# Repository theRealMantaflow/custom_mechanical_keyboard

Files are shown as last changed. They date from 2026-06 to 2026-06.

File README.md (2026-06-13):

# Custom STM32 Mechanical Keyboard

This repository contains the hardware design files (PCB schematics and mechanical enclosures) for a custom mechanical keyboard. The PCB is designed in **KiCad**, and the case/mechanical components are modeled in **FreeCAD**.

## Features

* **Microcontroller:** STM32F405RGT
* **Connectivity:** USB-C 2.0 with dedicated ESD protection (USBLC6-2SC6)
* **Switch Matrix:** 6x16 layout supporting up to 96 keys
* **Switches:** Cherry MX compatible, utilizing Khail hot-swap sockets
* **Anti-Ghosting:** Per-key diodes for full N-Key Rollover (NKRO)
* **Extras:** Support for a rotary encoder and broken-out SWD/I2C pins for easy debugging and expansion

## Repository Structure

* `/` - Contains the KiCad project, schematics, and PCB layout files.
* `/case/` - Contains the FreeCAD design files for the keyboard case and plate.
* `/pcbway_production/` - Contains the gerber files.

## Prerequisites & Environment Setup

Before opening the KiCad project files, you need to configure your KiCad environment with the appropriate custom libraries and plugins used in this design. 

### KiCad Package Installation

Follow these steps exactly to ensure all footprints and symbols load correctly:

1. **Add the ebastler repository:**
   * Open KiCad and go to the **Plugin and Content Manager**.
   * Click on **Manage Repositories** (usually at the bottom left).
   * Add a new repository with the following URL:
     [https://raw.githubusercontent.com/ebastler/KiCad-repository/main/repository.json](https://raw.githubusercontent.com/ebastler/KiCad-repository/main/repository.json)
2. **Install custom libraries:**
   * Switch the repository dropdown at the top of the Plugin Manager to the newly added `ebastler` repo.
   * Find and install the **`marbastlib`** package.
3. **Switch back to the official repository:**
   * Change the repository dropdown back to the official **KiCad** repository.
4. **Install required keyboard packages:**
   * Search for and install the **`Keyswitch KiCad Library`**.
   * *(Optional)* If you plan on modifying the PCB layout, install the **`Keyboard footprints placer`** plugin to make routing and placing switches easier.

Once these packages are installed, you can safely open the `.kicad_pro` file.

## Contributions

Feel free to fork this repository and submit pull requests if you have improvements for the PCB routing or case design. 

My Ko-fi link if you wanna support my efforts: Ko-fi [Kofi](https://ko-fi.com/mantaflow)

## Thanks

Inspired from: [Modern Hobbyist](https://www.youtube.com/watch?v=u13yRbBiRYM)

## License
This project is licensed under the **GNU General Public License v3.0 (GPL-3.0)**. See the [LICENSE](LICENSE.txt) file for more details.

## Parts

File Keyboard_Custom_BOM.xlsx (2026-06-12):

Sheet: Build Summary
Component Category | Total Parts Needed | Unique Components
Keyboard Items | 31 | 6
PCB Items | 211 | 18
Total (Active) | 242 | 24

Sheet: Full Parts List
Item Description | Quantity | Unit Price | Total | Category | Status | Purchase Link
Stabs | 12 | 32 | 384 | Keyboard Items | Active | https://neomacro.in/products/cherry-pcb-mount-stabilizers-clip-in
Stabs wire set | 1 | 400 | 400 | Keyboard Items | Active | https://neomacro.in/products/equalz-c3-stabilizer-wire-set
Stabs (optional) | 1 | 999 | 999 | Keyboard Items | Discarded | https://meckeys.com/shop/accessories/keyboard-accessories/more/glorious-goat-stabilizers/
sockets | 9 | 80 | 720 | Keyboard Items | Active | https://meckeys.com/shop/accessories/keyboard-accessories/key-switches/kailh-hot-swap-socket/
switches (HMx Hyacinth v2) | 9 | 360 | 3240 | Keyboard Items | Active | https://meckeys.com/shop/accessories/keyboard-accessories/key-switches/hmx-hyacinth-v2-switch/
switches (Kailh Box Cream Pro) | 9 | 380 | 3420 | Keyboard Items | Discarded | https://meckeys.com/shop/accessories/keyboard-accessories/key-switches/kailh-box-cream-pro-switch/
MCU (STM32F405RGT6) | 2 | 462 | 924 | PCB Items | Active | https://robu.in/product/stm32f405rgt6-stmicroelectronics-arm-mcu-advanced-connectivity-and-encryption-stm32-family-stm32f4-series-microcontrollers-2/
12Mhz crystals HC49/US | 5 | 27.95 | 139.75 | PCB Items | Active | https://www.mouser.in/ProductDetail/ABRACON/ABLS2-12.000MHZ-D4Y-T?qs=LoTOQoUkC8Rn80rn3Dp9%252Bw%3D%3D
1N4148 SOD-123-2 | 100 | 3.91 | 391 | PCB Items | Active | https://www.mouser.in/ProductDetail/Panjit/1N4148W_R1_00001?qs=sPbYRqrBIVnqVztCqPNVrw%3D%3D
22pF 2012 | 10 | 14.07 | 140.7 | PCB Items | Active | https://www.mouser.in/ProductDetail/KYOCERA-AVX/0805ZA220JAT2A?qs=qVfB0%2FDaMDayn2JkoZWS9w%3D%3D
0.01uF 2012 | 10 | 15.56 | 155.6 | PCB Items | Active | https://www.mouser.in/ProductDetail/KYOCERA-AVX/0805YC103JAT2A?qs=hDfa8caAWT981330vF6Hgg%3D%3D
0.1uF 2012 | 10 | 11.83 | 118.3 | PCB Items | Active | https://www.mouser.in/ProductDetail/KYOCERA-AVX/KAM21BR71H104JM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
2.2uF 2012 | 10 | 23.57 | 235.7 | PCB Items | Active | https://www.mouser.in/ProductDetail/KYOCERA-AVX/0805YC225JAT2A?qs=%252BdQmOuGyFcHAs%2FdSKfbQcg%3D%3D
10uF 2012 | 10 | 7.27 | 72.7 | PCB Items | Active | https://www.mouser.in/ProductDetail/Walsin/0805B106K6R3CT?qs=sGAEpiMZZMuMW9TJLBQkXoaTank9xe3KyjArHnZbXP4%3D
5.1kOhm 2012 | 10 | 1.86 | 18.6 | PCB Items | Active | https://www.mouser.in/ProductDetail/YAGEO/RC0805JR-105K1L?qs=sGAEpiMZZMtlubZbdhIBIEgN9MQql2m6y5lVZltd6Tw%3D
10kOhm 2012 | 10 | 6.71 | 67.1 | PCB Items | Active | https://www.mouser.in/ProductDetail/SEI-Stackpole/RMCA0805JT10K0-UP?qs=IPgv5n7u5Qax6yYsSvtfnA%3D%3D
PPTC Fuse 3216 | 5 | 39.14 | 195.7 | PCB Items | Active | https://www.mouser.in/ProductDetail/Eaton-Electronics/PTSA120613V050
rotary encoder | 2 | 231.09 | 462.18 | PCB Items | Active | https://www.mouser.in/ProductDetail/Bourns/PEC11L-4020F-S0020?qs=fgHA1UgJI8CzObWXJBveJQ%3D%3D
Push Button | 10 | 8.67 | 86.7 | PCB Items | Active | https://www.mouser.in/ProductDetail/Same-Sky/TS02-66-70-BK-260-LCR-D?qs=A6eO%252BMLsxmRxQEfk53wqSQ%3D%3D
USB-C port with through-hole pins | 3 | 123 | 369 | PCB Items | Active | https://www.mouser.in/ProductDetail/Same-Sky/UJ20-C-H-G-SMT-TR?qs=vvQtp7zwQdMB%2FjSfD6wTAw%3D%3D
Voltage Regulator SOT-25-5 | 3 | 24.23 | 72.69 | PCB Items | Active | https://www.mouser.in/ProductDetail/Diodes-Incorporated/AP2112K-3.3TRG1?qs=x6A8l6qLYDDPYHosCdzh%2FA%3D%3D
USB TVS Diode | 10 | 27.86 | 278.6 | PCB Items | Active | https://www.mouser.in/ProductDetail/STMicroelectronics/USBLC6-2SC6?qs=po45yt2pPpu%2FhNIlwQdTlg%3D%3D
1uF 2012 | 10 | 15.37 | 153.7 | PCB Items | Discarded | https://www.mouser.in/ProductDetail/KYOCERA-AVX/KGM21AR71C105JU?qs=Jm2GQyTW%2FbgRn%252Bi87%2FZsQQ%3D%3D
PCB (converted from USD, not including import duty) | 1 | 3343.68 | 3343.68 | PCB Items | Active | JLC PCB
Grand Total (Active): | 11816

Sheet: Pivot Table_Full Parts List_1
Status | Active
Item Description | Sum - Total
0.01uF 2012 | 155.6
0.1uF 2012 | 118.3
10kOhm 2012 | 67.1
10uF 2012 | 72.7
12Mhz crystals HC49/US | 139.75
1N4148 SOD-123-2 | 391
2.2uF 2012 | 235.7
22pF 2012 | 140.7
5.1kOhm 2012 | 18.6
MCU (STM32F405RGT6) | 924
PCB (not including import duty) | 3343.68
PPTC Fuse 3216 | 195.7
Push Button | 86.7
rotary encoder | 462.18
sockets | 720
Stabs | 384
Stabs wire set | 400
switches (HMx Hyacinth v2) | 3240
USB TVS Diode | 278.6
USB-C port with through-hole pins | 369
Voltage Regulator SOT-25-5 | 72.69
Total Result | 11816

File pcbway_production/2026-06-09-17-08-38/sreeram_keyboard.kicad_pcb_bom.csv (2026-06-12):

Designator | Quantity | Value | Footprint | Package | MPN | DNP | Mount_Type | KiLib_Generator
C1, C13, C15, C3, C5, C6, C7, C8 | 8 | 0.1uF | C_0805_2012Metric_Pad1.18x1.45mm_HandSolder |  |  |  | smt | SMD_2terminal_chip_molded
C10, C9 | 2 | 2.2uF | C_0805_2012Metric_Pad1.18x1.45mm_HandSolder |  |  |  | smt | SMD_2terminal_chip_molded
C11, C12 | 2 | 22pF | C_0805_2012Metric_Pad1.18x1.45mm_HandSolder |  |  |  | smt | SMD_2terminal_chip_molded
C14, C2, C4 | 3 | 10uF | C_0805_2012Metric_Pad1.18x1.45mm_HandSolder |  |  |  | smt | SMD_2terminal_chip_molded
C16, C17 | 2 | 0.01uF | C_0805_2012Metric_Pad1.18x1.45mm_HandSolder |  |  |  | smt | SMD_2terminal_chip_molded
D1, D10, D11, D12, D13, D14, D15, D16, D17, D18, D19, D2, D20, D21, D22, D23, D24, D25, D26, D27, D28, D29, D3, D30, D31, D32, D33, D34, D35, D36, D37, D38, D39, D4, D40, D41, D42, D43, D44, D45, D46, D47, D48, D49, D5, D50, D51, D52, D53, D54, D55, D56, D57, D58, D59, D6, D60, D61, D62, D63, D64, D65, D66, D67, D68, D69, D7, D70, D71, D72, D73, D74, D75, D76, D77, D78, D79, D8, D80, D81, D82, D83, D84, D85, D86, D9 | 86 | D | D_SOD-123 |  |  |  | smt
F1 | 1 | 550mA | Fuse_1206_3216Metric_Pad1.42x1.75mm_HandSolder |  |  |  | smt | SMD_2terminal_chip_molded
J1 | 1 | USB_C_Receptacle_USB2.0_14P | USB_C_Receptacle_GCT_USB4085 |  |  |  | tht
J2, J3 | 2 | Conn_01x10_Pin | PinHeader_1x10_P2.54mm_Vertical |  |  |  | tht | connector/pin_header_socket
MX1, MX10, MX11, MX12, MX13, MX14, MX15, MX16, MX17, MX18, MX19, MX2, MX20, MX21, MX22, MX23, MX24, MX25, MX26, MX27, MX28, MX29, MX3, MX30, MX31, MX32, MX33, MX34, MX35, MX36, MX37, MX38, MX39, MX4, MX40, MX41, MX42, MX43, MX44, MX45, MX46, MX47, MX48, MX49, MX5, MX50, MX51, MX52, MX53, MX54, MX55, MX56, MX57, MX58, MX59, MX6, MX60, MX61, MX62, MX63, MX64, MX65, MX66, MX67, MX68, MX69, MX7, MX70, MX71, MX72, MX73, MX74, MX75, MX76, MX77, MX78, MX79, MX8, MX80, MX81, MX82, MX83, MX84, MX85, MX86, MX9 | 86 | MX_SW_HS | SW_MX_HS_S_CPG151101S11_1u |  |  |  | smt
R1, R2 | 2 | 5.1k | R_0805_2012Metric_Pad1.20x1.40mm_HandSolder |  |  |  | smt | SMD_2terminal_chip_molded
R3, R5, R6, R7 | 4 | 10k | R_0805_2012Metric_Pad1.20x1.40mm_HandSolder |  |  |  | smt | SMD_2terminal_chip_molded
R4 | 1 | 100k | R_0805_2012Metric_Pad1.20x1.40mm_HandSolder |  |  |  | smt | SMD_2terminal_chip_molded
S6 | 1 | TS02-66-70-BK-260-LCR-D | TS0266100BK100LCRD |  |  |  | tht
U1 | 1 | STM32F405RGTx | LQFP-64_10x10mm_P0.5mm |  |  |  | smt | package/gullwing
U2 | 1 | AP2112K-3.3 | SOT95P285X140-5N |  |  |  | smt
U3 | 1 | USBLC6-2SC6 | SOT-23-6 |  |  |  | smt | package/gullwing
U4 | 1 | PEC11L-4020F-S0020 | PEC11L4120FS0020 |  |  |  | tht
Y1 | 1 | 12Mhz | ABLS |  |  |  | smt

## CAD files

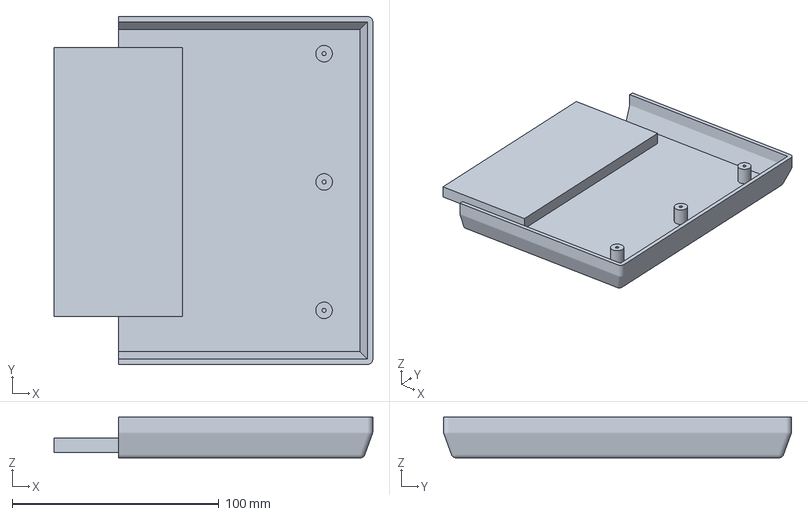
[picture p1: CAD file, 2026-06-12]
case/exports/3MF/case-RightSlice.3mf
154.0 x 168.2 x 19.8 mm

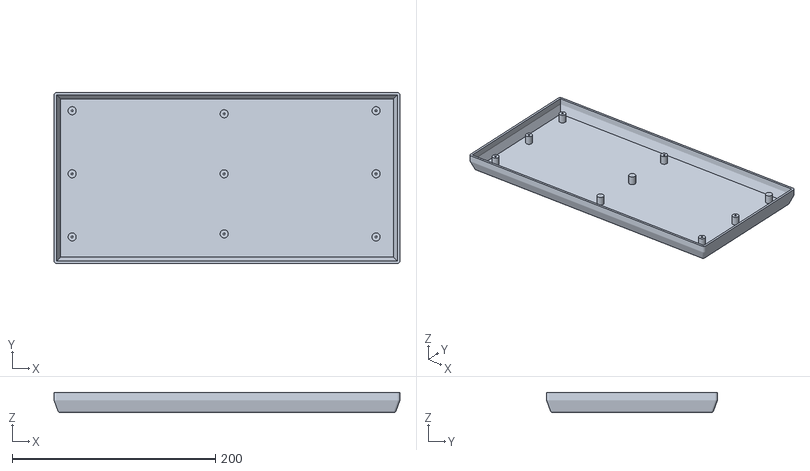
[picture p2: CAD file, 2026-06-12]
case/exports/STL/case/case-Body.stl
340.2 x 168.2 x 19.8

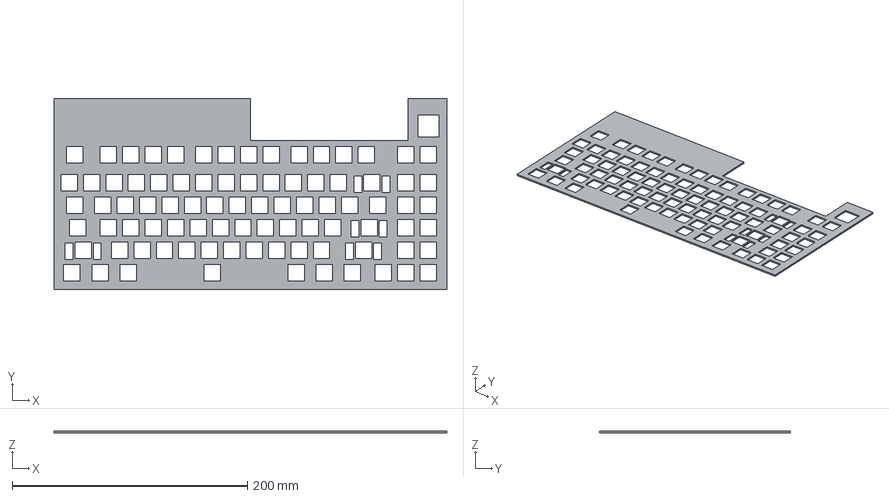
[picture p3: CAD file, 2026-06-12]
case/exports/STP/front_plate-Body.step
333.8 x 162.2 x 1.50 mm

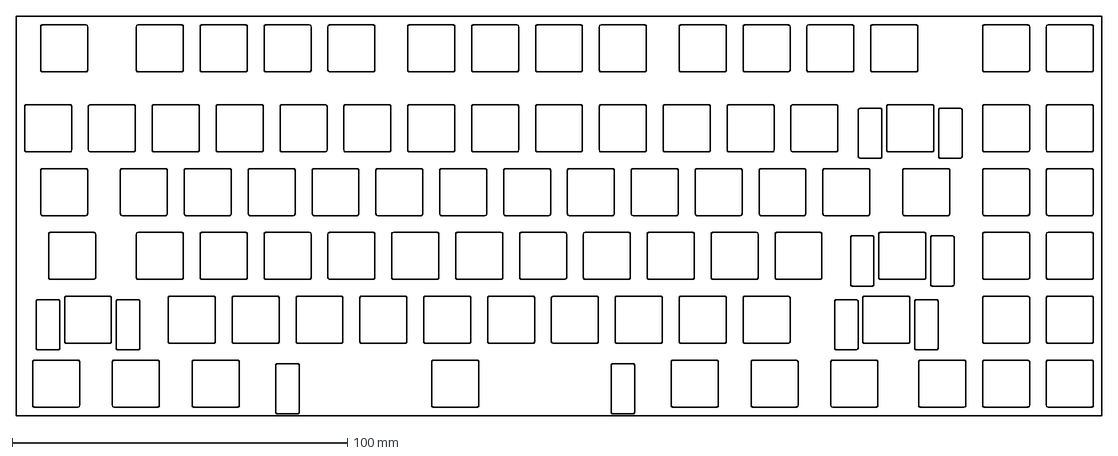
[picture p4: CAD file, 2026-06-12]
case/plate-2026-06-02T06_51_52.090Z.dxf
323.9 x 119.1 mm

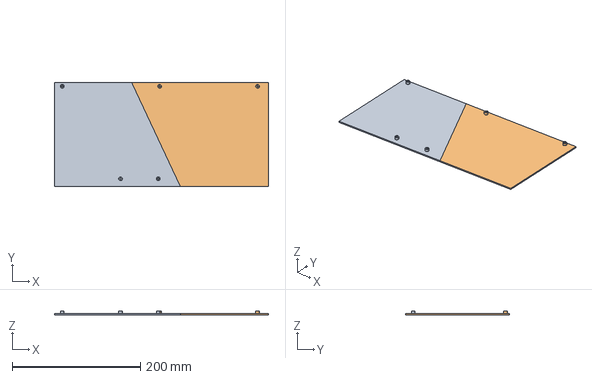
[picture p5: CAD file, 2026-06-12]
case/back_plate.FCStd
333.8 x 162.2 x 6.00 mm
LeftSlice
RightSlice

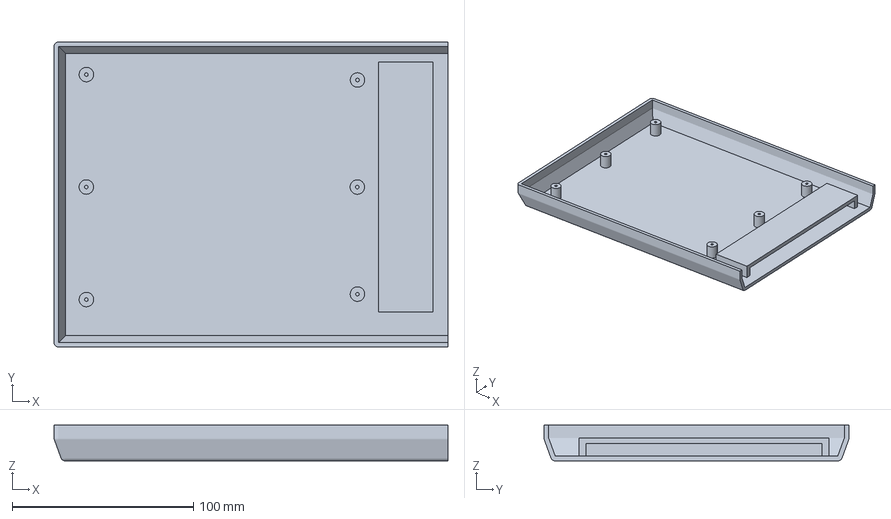
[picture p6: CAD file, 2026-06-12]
case/exports/3MF/case-LeftSlice.3mf
217.3 x 168.2 x 19.8 mm

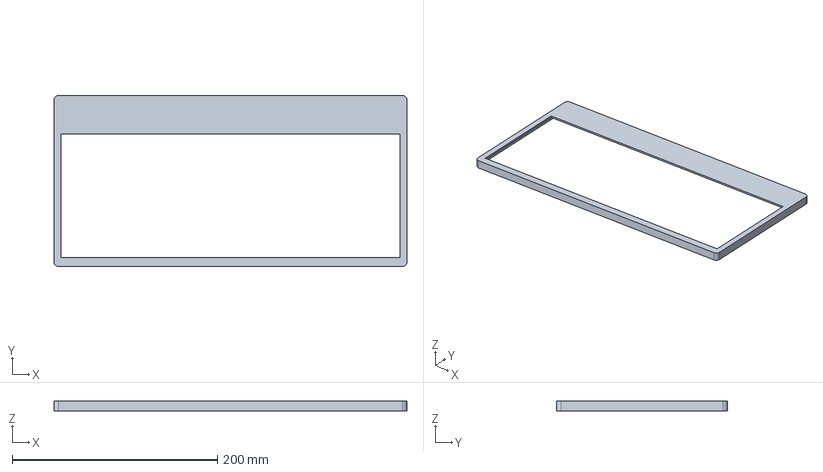
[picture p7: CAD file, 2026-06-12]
case/front_cover.FCStd
344.2 x 167.0 x 9.40 mm

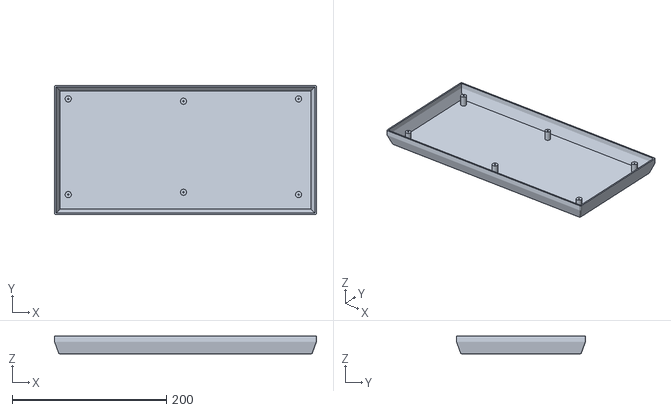
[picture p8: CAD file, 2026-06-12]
case/case-Body.stl
339.9 x 167.4 x 23.0

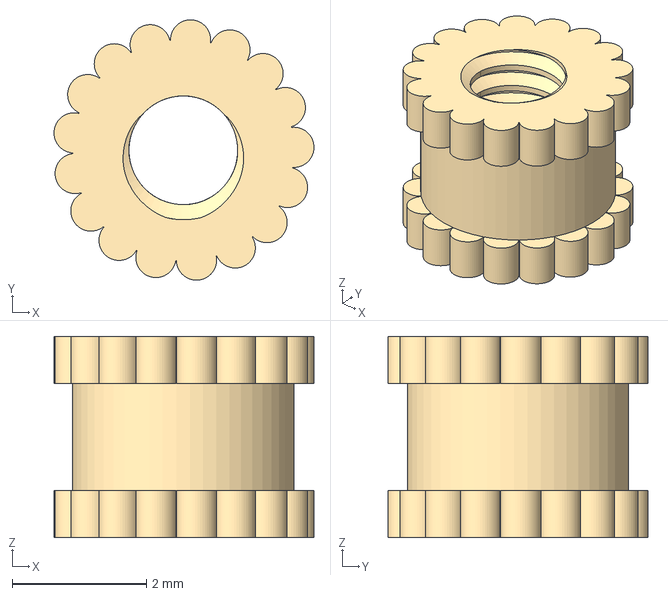
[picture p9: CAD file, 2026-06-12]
case/BI_M2x3_heat_insert.step
3.88 x 3.88 x 3.00 mm

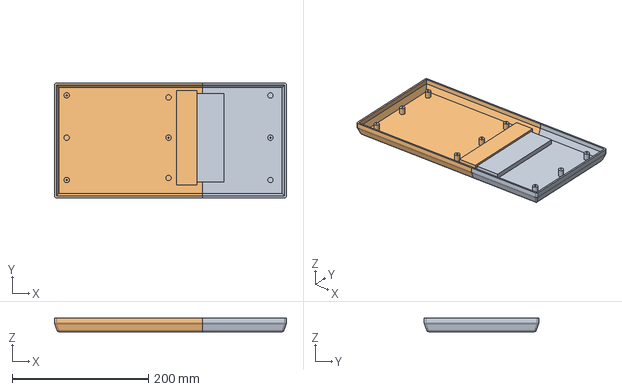
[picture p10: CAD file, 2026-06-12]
case/case.FCStd
340.2 x 168.2 x 19.8 mm
RightSlice
LeftSlice

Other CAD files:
case/front_plate.FCStd
case/exports/3MF/Old/front_plate-Body.3mf
case/exports/3MF/Old/front_cover-Body.3mf
case/exports/3MF/Old/case-Body.3mf
case/exports/3MF/Old/front_cover-BodyPocket.3mf
case/exports/3MF/Old/back_plate-Body.3mf
case/exports/STL/front_plate-Body.stl

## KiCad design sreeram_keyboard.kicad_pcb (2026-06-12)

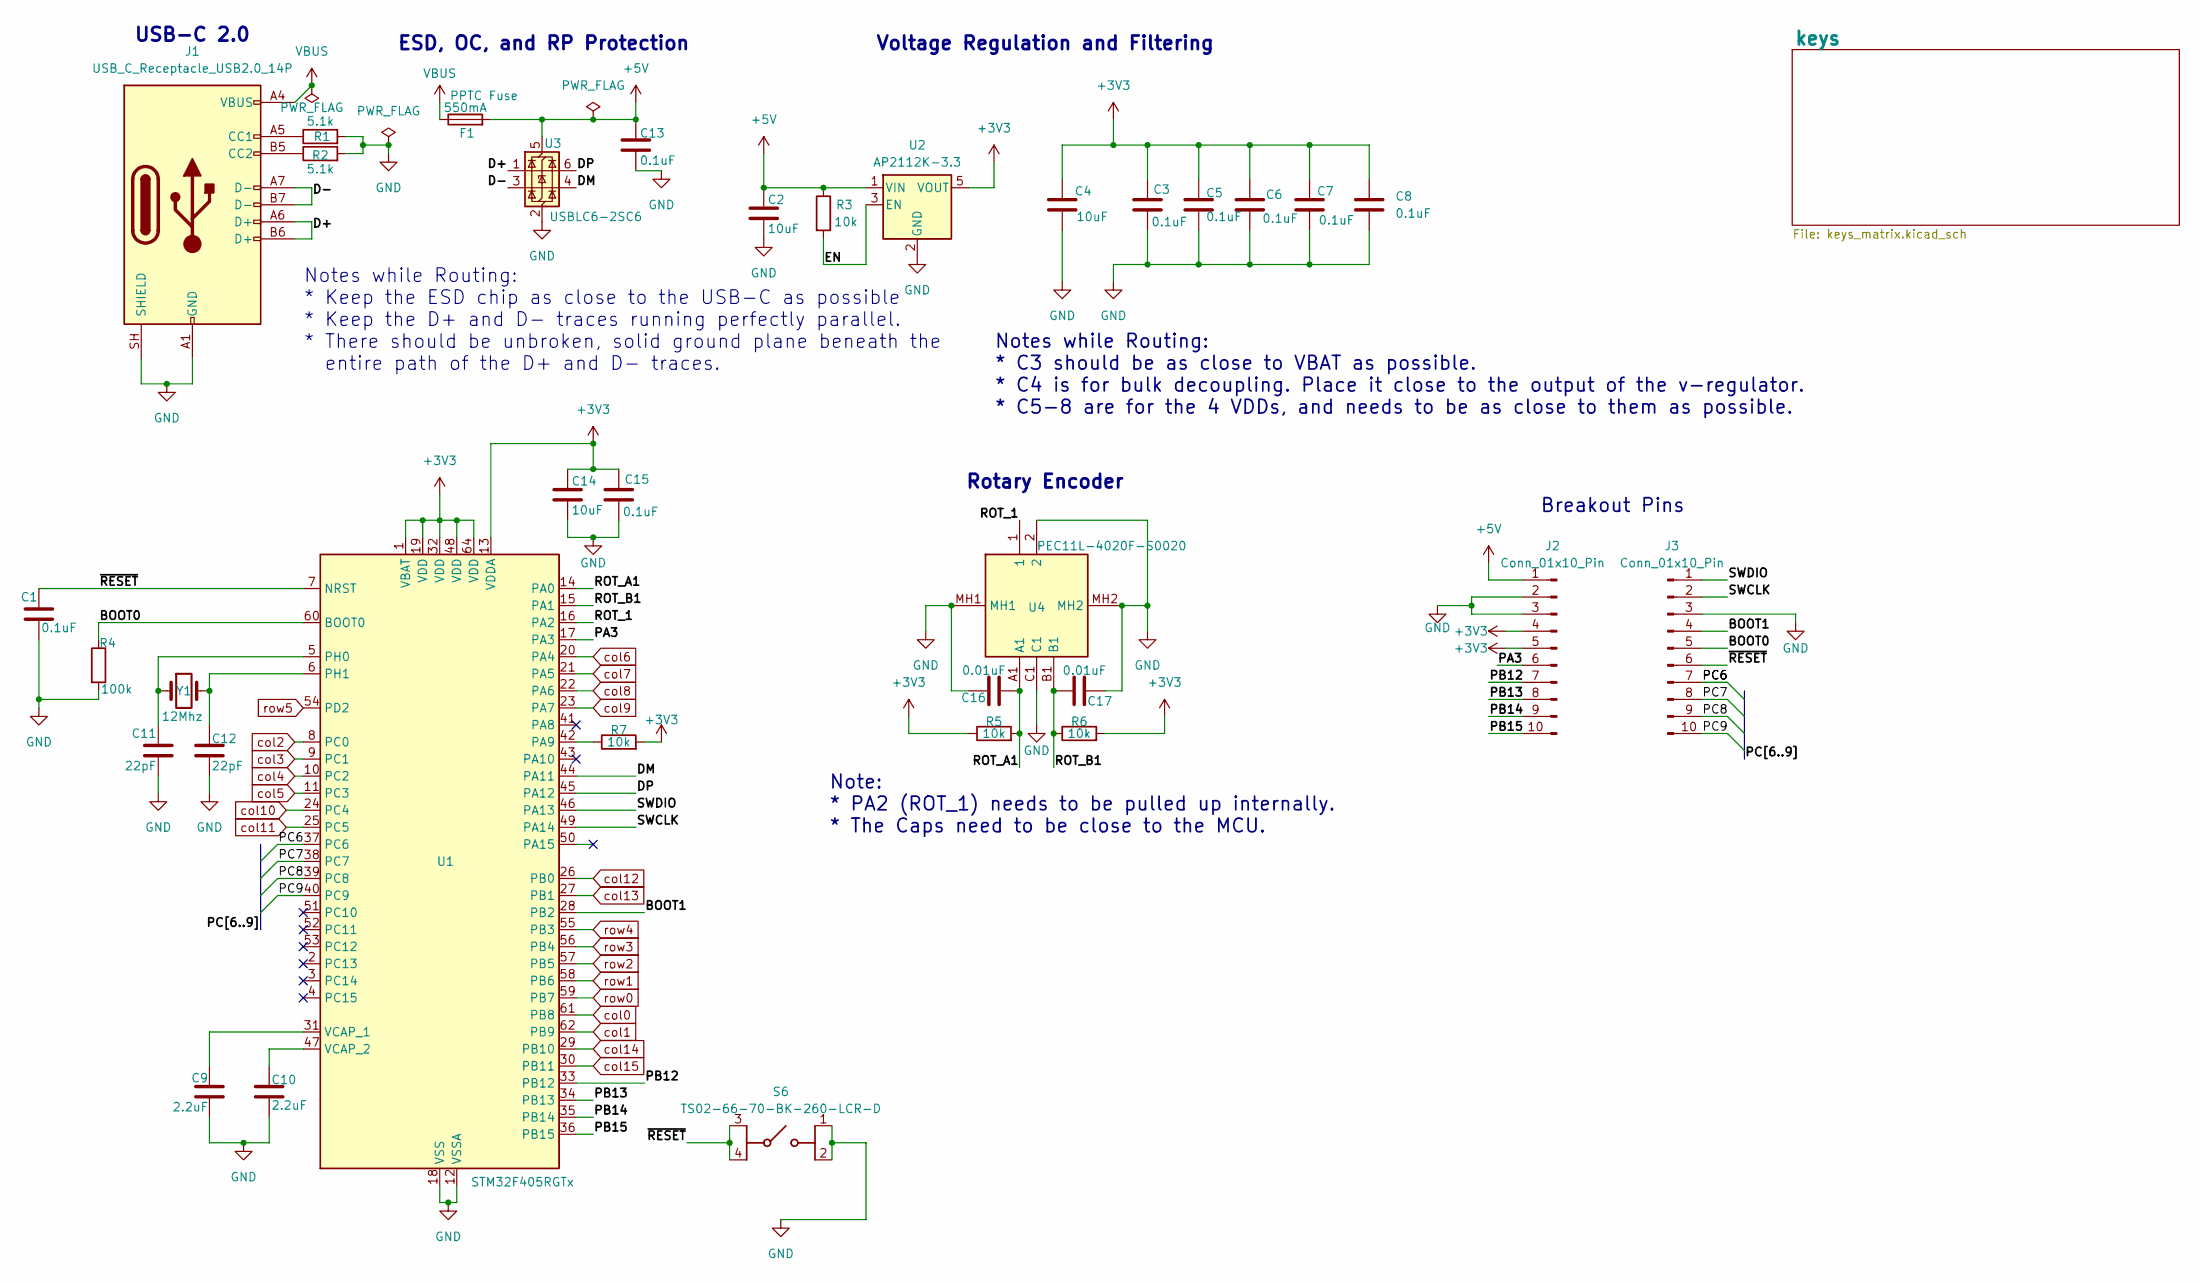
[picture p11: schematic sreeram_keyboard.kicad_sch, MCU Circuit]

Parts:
C1, C3, C5, C6, C7, C8, C13, C15: 0.1uF; C_0805_2012Metric_Pad1.18x1.45mm_HandSolder
C2, C4, C14: 10uF; C_0805_2012Metric_Pad1.18x1.45mm_HandSolder
C9, C10: 2.2uF; C_0805_2012Metric_Pad1.18x1.45mm_HandSolder
C11, C12: 22pF; C_0805_2012Metric_Pad1.18x1.45mm_HandSolder
C16, C17: 0.01uF; C_0805_2012Metric_Pad1.18x1.45mm_HandSolder
F1: 550mA; Fuse_1206_3216Metric_Pad1.42x1.75mm_HandSolder
J1: USB_C_Receptacle_USB2.0_14P; USB_C_Receptacle_GCT_USB4085
J2, J3: Conn_01x10_Pin; PinHeader_1x10_P2.54mm_Vertical
R1, R2: 5.1k; R_0805_2012Metric_Pad1.20x1.40mm_HandSolder
R3, R5, R6, R7: 10k; R_0805_2012Metric_Pad1.20x1.40mm_HandSolder
R4: 100k; R_0805_2012Metric_Pad1.20x1.40mm_HandSolder
S6: TS02-66-70-BK-260-LCR-D; TS0266100BK100LCRD; Mouser Part Number 179-TS026670BK260LCR
U1: STM32F405RGTx; LQFP-64_10x10mm_P0.5mm
U2: AP2112K-3.3; SOT95P285X140-5N
U3: USBLC6-2SC6; SOT-23-6
U4: PEC11L-4020F-S0020; PEC11L4120FS0020; Mouser Part Number 652-PEC11L4020FS0020
Y1: 12Mhz; ABLS

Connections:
+3V3: C3.1, C4.1, C5.1, C6.1, C7.1, C8.1, C14.1, C15.1, J2.4, J2.5, R5.1, R6.2, R7.2, U1.1 (VBAT), U1.13 (VDDA), U1.19 (VDD), U1.32 (VDD), U1.48 (VDD), U1.64 (VDD), U2.5 (VOUT)
+5V: C2.1, C13.1, F1.2, J2.1, R3.1, U2.1 (VIN), U3.5 (VBUS)
/BOOT0: J3.5, R4.1, U1.60 (BOOT0)
/BOOT1: J3.4, U1.28 (PB2)
/D+: J1.A6 (D+), J1.B6 (D+), U3.1 (I/O1)
/D-: J1.A7 (D-), J1.B7 (D-), U3.3 (I/O2)
/DM: U1.44 (PA11), U3.4 (I/O2)
/DP: U1.45 (PA12), U3.6 (I/O1)
/EN: R3.2, U2.3 (EN)
/PA3: J2.6, U1.17 (PA3)
/PB12: J2.7, U1.33 (PB12)
/PB13: J2.8, U1.34 (PB13)
/PB14: J2.9, U1.35 (PB14)
/PB15: J2.10, U1.36 (PB15)
/PC6: J3.7, U1.37 (PC6)
/PC7: J3.8, U1.38 (PC7)
/PC8: J3.9, U1.39 (PC8)
/PC9: J3.10, U1.40 (PC9)
/ROT_1: U1.16 (PA2), U4.1
/ROT_A1: C16.2, R5.2, U1.14 (PA0), U4.A1
/ROT_B1: C17.1, R6.1, U1.15 (PA1), U4.B1
/SWCLK: J3.2, U1.49 (PA14)
/SWDIO: J3.1, U1.46 (PA13)
/~RESET: C1.1, J3.6, S6.3 (COM_1), S6.4 (COM_2), U1.7 (NRST)
GND: C1.2, C2.2, C3.2, C4.2, C5.2, C6.2, C7.2, C8.2, C9.2, C10.2, C11.2, C12.2, C13.2, C14.2, C15.2, C16.1, C17.2, J1.A1 (GND), J1.A12 (GND), J1.B1 (GND), J1.B12 (GND), J1.SH (SHIELD), J2.2, J2.3, J3.3, R1.2, R2.2, R4.2, S6.1 (NO_1), S6.2 (NO_2), U1.12 (VSSA), U1.18 (VSS), U1.63 (VSS), U2.2 (GND), U3.2 (GND), U4.2, U4.C1, U4.MH1, U4.MH2
unnamed: J1.A5 (CC1), R1.1
unnamed: J1.B5 (CC2), R2.1
unnamed: R7.1, U1.42 (PA9)
unnamed: C11.1, U1.5 (PH0), Y1.1
unnamed: C12.1, U1.6 (PH1), Y1.2
unnamed: C9.1, U1.31 (VCAP_1)
unnamed: C10.1, U1.47 (VCAP_2)
VBUS: F1.1, J1.A4 (VBUS), J1.A9 (VBUS), J1.B4 (VBUS), J1.B9 (VBUS)
col0: U1.61 (PB8); also elsewhere on the board
col1: U1.62 (PB9); also elsewhere on the board
col2: U1.8 (PC0); also elsewhere on the board
col3: U1.9 (PC1); also elsewhere on the board
col4: U1.10 (PC2); also elsewhere on the board
col5: U1.11 (PC3); also elsewhere on the board
col6: U1.20 (PA4); also elsewhere on the board
col7: U1.21 (PA5); also elsewhere on the board
col8: U1.22 (PA6); also elsewhere on the board
col9: U1.23 (PA7); also elsewhere on the board
col10: U1.24 (PC4); also elsewhere on the board
col11: U1.25 (PC5); also elsewhere on the board
col12: U1.26 (PB0); also elsewhere on the board
col13: U1.27 (PB1); also elsewhere on the board
col14: U1.29 (PB10); also elsewhere on the board
col15: U1.30 (PB11); also elsewhere on the board
row0: U1.59 (PB7); also elsewhere on the board
row1: U1.58 (PB6); also elsewhere on the board
row2: U1.57 (PB5); also elsewhere on the board
row3: U1.56 (PB4); also elsewhere on the board
row4: U1.55 (PB3); also elsewhere on the board
row5: U1.54 (PD2); also elsewhere on the board

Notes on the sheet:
Notes while Routing: * C3 should be as close to VBAT as possible. * C4 is for bulk decoupling. Place it close to the output of the v-regulator. * C5-8 are for the 4 VDDs, and needs to be as close to them as possible.
Notes while Routing: * Keep the ESD chip as close to the USB-C as possible * Keep the D+ and D- traces running perfectly parallel. * There should be unbroken, solid ground plane beneath the entire path of the D+ and D- traces.
USB-C 2.0
Voltage Regulation and Filtering
ESD, OC, and RP Protection
Note: * PA2 (ROT_1) needs to be pulled up internally. * The Caps need to be close to the MCU.
Rotary Encoder
Breakout Pins

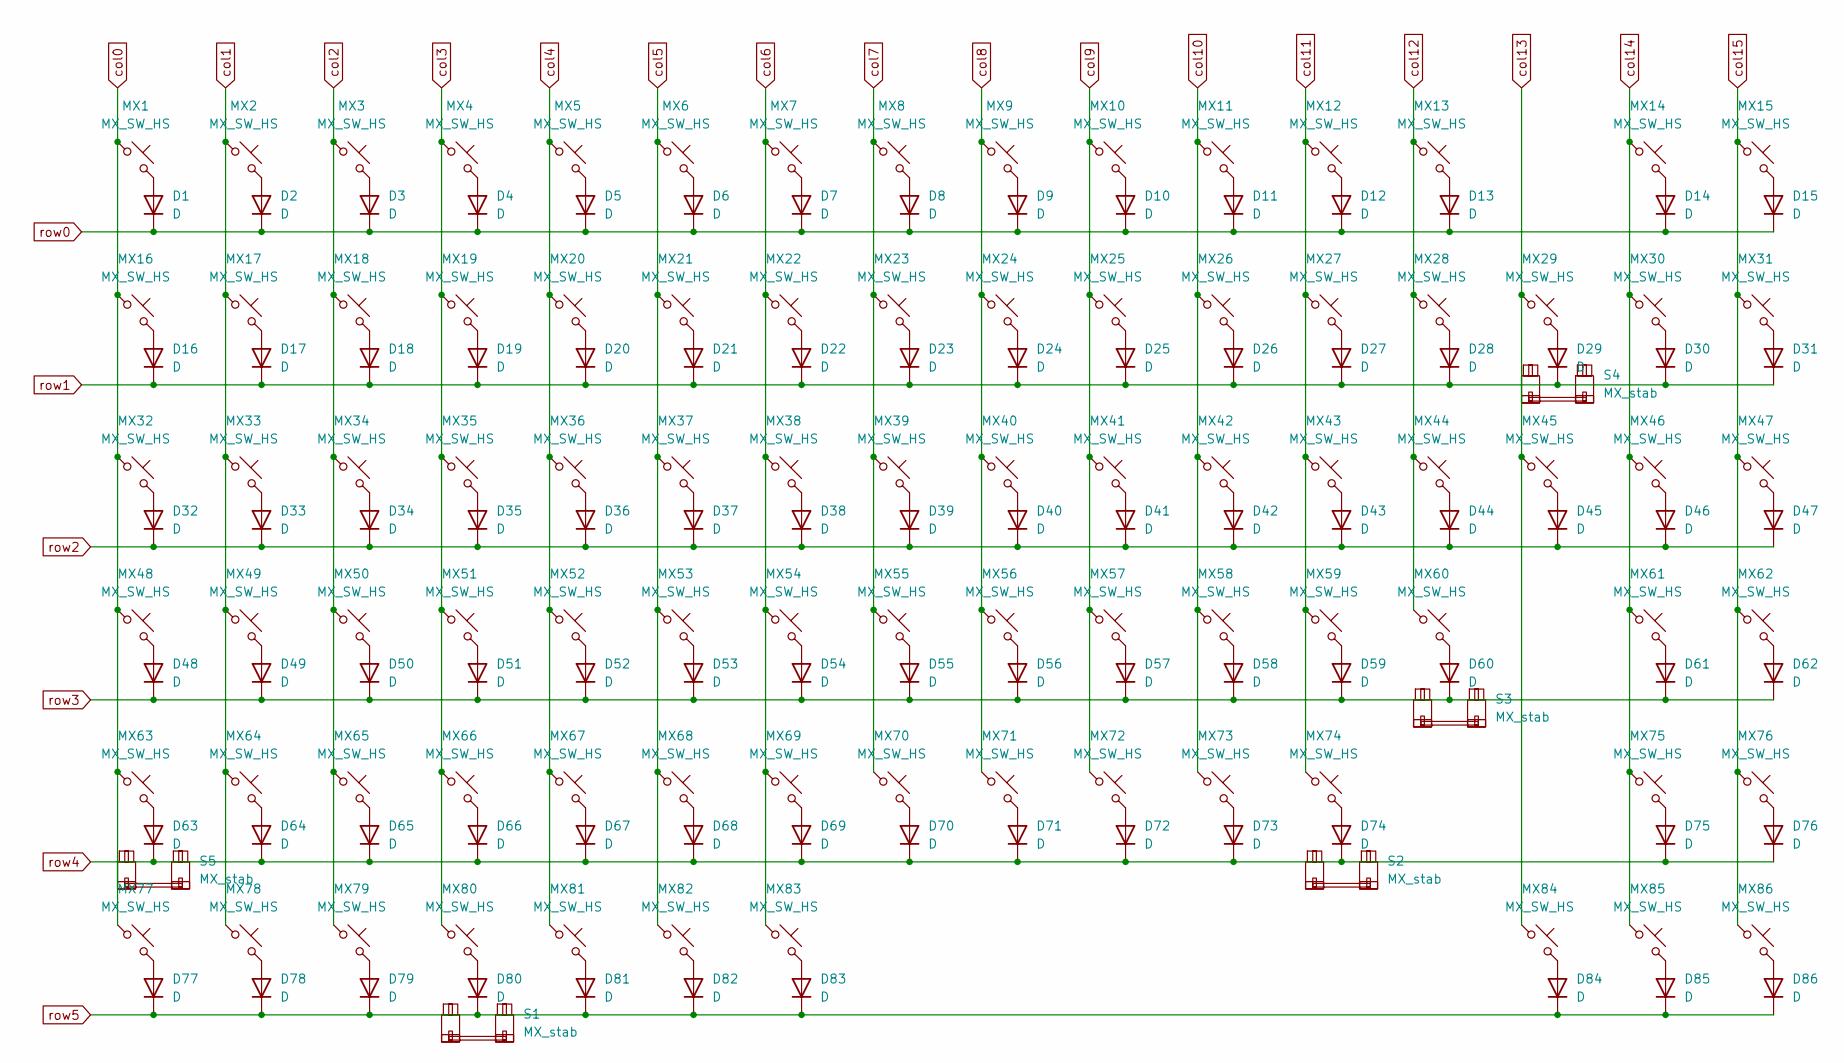
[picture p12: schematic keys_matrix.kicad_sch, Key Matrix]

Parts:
D1, D2, D3, D4, D5, D6, D7, D8, D9, D10, D11, D12, D13, D14, D15, D16, D17, D18, D19, D20, D21, D22, D23, D24, D25, D26, D27, D28, D29, D30, D31, D32, D33, D34, D35, D36, D37, D38, D39, D40, D41, D42, D43, D44, D45, D46, D47, D48, D49, D50, D51, D52, D53, D54, D55, D56, D57, D58, D59, D60, D61, D62, D63, D64, D65, D66, D67, D68, D69, D70, D71, D72, D73, D74, D75, D76, D77, D78, D79, D80, D81, D82, D83, D84, D85, D86: D; D_SOD-123
MX1, MX2, MX3, MX4, MX5, MX6, MX7, MX8, MX9, MX10, MX11, MX12, MX13, MX14, MX15, MX16, MX17, MX18, MX19, MX20, MX21, MX22, MX23, MX24, MX25, MX26, MX27, MX28, MX29, MX30, MX31, MX32, MX33, MX34, MX35, MX36, MX37, MX38, MX39, MX40, MX41, MX42, MX43, MX44, MX45, MX46, MX47, MX48, MX49, MX50, MX51, MX52, MX53, MX54, MX55, MX56, MX57, MX58, MX59, MX60, MX61, MX62, MX63, MX64, MX65, MX66, MX67, MX68, MX69, MX70, MX71, MX72, MX73, MX74, MX75, MX76, MX77, MX78, MX79, MX80, MX81, MX82, MX83, MX84, MX85, MX86: MX_SW_HS; SW_MX_HS_S_CPG151101S11_1u
S1: MX_stab; STAB_MX_P_6.25u
S2, S3, S4, S5: MX_stab; STAB_MX_P_2u

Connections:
unnamed: D1.2 (A), MX1.2
unnamed: D2.2 (A), MX2.2
unnamed: D3.2 (A), MX3.2
unnamed: D4.2 (A), MX4.2
unnamed: D5.2 (A), MX5.2
unnamed: D6.2 (A), MX6.2
unnamed: D7.2 (A), MX7.2
unnamed: D8.2 (A), MX8.2
unnamed: D9.2 (A), MX9.2
unnamed: D10.2 (A), MX10.2
unnamed: D11.2 (A), MX11.2
unnamed: D12.2 (A), MX12.2
unnamed: D13.2 (A), MX13.2
unnamed: D14.2 (A), MX14.2
unnamed: D15.2 (A), MX15.2
unnamed: D16.2 (A), MX16.2
unnamed: D17.2 (A), MX17.2
unnamed: D18.2 (A), MX18.2
unnamed: D19.2 (A), MX19.2
unnamed: D20.2 (A), MX20.2
unnamed: D21.2 (A), MX21.2
unnamed: D22.2 (A), MX22.2
unnamed: D23.2 (A), MX23.2
unnamed: D24.2 (A), MX24.2
unnamed: D25.2 (A), MX25.2
unnamed: D26.2 (A), MX26.2
unnamed: D27.2 (A), MX27.2
unnamed: D28.2 (A), MX28.2
unnamed: D29.2 (A), MX29.2
unnamed: D30.2 (A), MX30.2
unnamed: D31.2 (A), MX31.2
unnamed: D32.2 (A), MX32.2
unnamed: D33.2 (A), MX33.2
unnamed: D34.2 (A), MX34.2
unnamed: D35.2 (A), MX35.2
unnamed: D36.2 (A), MX36.2
unnamed: D37.2 (A), MX37.2
unnamed: D38.2 (A), MX38.2
unnamed: D39.2 (A), MX39.2
unnamed: D40.2 (A), MX40.2
unnamed: D41.2 (A), MX41.2
unnamed: D42.2 (A), MX42.2
unnamed: D43.2 (A), MX43.2
unnamed: D44.2 (A), MX44.2
unnamed: D45.2 (A), MX45.2
unnamed: D46.2 (A), MX46.2
unnamed: D47.2 (A), MX47.2
unnamed: D48.2 (A), MX48.2
unnamed: D49.2 (A), MX49.2
unnamed: D50.2 (A), MX50.2
unnamed: D51.2 (A), MX51.2
unnamed: D52.2 (A), MX52.2
unnamed: D53.2 (A), MX53.2
unnamed: D54.2 (A), MX54.2
unnamed: D55.2 (A), MX55.2
unnamed: D56.2 (A), MX56.2
unnamed: D57.2 (A), MX57.2
unnamed: D58.2 (A), MX58.2
unnamed: D59.2 (A), MX59.2
unnamed: D60.2 (A), MX60.2
unnamed: D61.2 (A), MX61.2
unnamed: D62.2 (A), MX62.2
unnamed: D63.2 (A), MX63.2
unnamed: D64.2 (A), MX64.2
unnamed: D65.2 (A), MX65.2
unnamed: D66.2 (A), MX66.2
unnamed: D67.2 (A), MX67.2
unnamed: D68.2 (A), MX68.2
unnamed: D69.2 (A), MX69.2
unnamed: D70.2 (A), MX70.2
unnamed: D71.2 (A), MX71.2
unnamed: D72.2 (A), MX72.2
unnamed: D73.2 (A), MX73.2
unnamed: D74.2 (A), MX74.2
unnamed: D75.2 (A), MX75.2
unnamed: D76.2 (A), MX76.2
unnamed: D77.2 (A), MX77.2
unnamed: D78.2 (A), MX78.2
unnamed: D79.2 (A), MX79.2
unnamed: D80.2 (A), MX80.2
unnamed: D81.2 (A), MX81.2
unnamed: D82.2 (A), MX82.2
unnamed: D83.2 (A), MX83.2
unnamed: D84.2 (A), MX84.2
unnamed: D85.2 (A), MX85.2
unnamed: D86.2 (A), MX86.2
col0: MX1.1, MX16.1, MX32.1, MX48.1, MX63.1, MX77.1; also elsewhere on the board
col1: MX2.1, MX17.1, MX33.1, MX49.1, MX64.1, MX78.1; also elsewhere on the board
col2: MX3.1, MX18.1, MX34.1, MX50.1, MX65.1, MX79.1; also elsewhere on the board
col3: MX4.1, MX19.1, MX35.1, MX51.1, MX66.1, MX80.1; also elsewhere on the board
col4: MX5.1, MX20.1, MX36.1, MX52.1, MX67.1, MX81.1; also elsewhere on the board
col5: MX6.1, MX21.1, MX37.1, MX53.1, MX68.1, MX82.1; also elsewhere on the board
col6: MX7.1, MX22.1, MX38.1, MX54.1, MX69.1, MX83.1; also elsewhere on the board
col7: MX8.1, MX23.1, MX39.1, MX55.1, MX70.1; also elsewhere on the board
col8: MX9.1, MX24.1, MX40.1, MX56.1, MX71.1; also elsewhere on the board
col9: MX10.1, MX25.1, MX41.1, MX57.1, MX72.1; also elsewhere on the board
col10: MX11.1, MX26.1, MX42.1, MX58.1, MX73.1; also elsewhere on the board
col11: MX12.1, MX27.1, MX43.1, MX59.1, MX74.1; also elsewhere on the board
col12: MX13.1, MX28.1, MX44.1, MX60.1; also elsewhere on the board
col13: MX29.1, MX45.1, MX84.1; also elsewhere on the board
col14: MX14.1, MX30.1, MX46.1, MX61.1, MX75.1, MX85.1; also elsewhere on the board
col15: MX15.1, MX31.1, MX47.1, MX62.1, MX76.1, MX86.1; also elsewhere on the board
row0: D1.1 (K), D2.1 (K), D3.1 (K), D4.1 (K), D5.1 (K), D6.1 (K), D7.1 (K), D8.1 (K), D9.1 (K), D10.1 (K), D11.1 (K), D12.1 (K), D13.1 (K), D14.1 (K), D15.1 (K); also elsewhere on the board
row1: D16.1 (K), D17.1 (K), D18.1 (K), D19.1 (K), D20.1 (K), D21.1 (K), D22.1 (K), D23.1 (K), D24.1 (K), D25.1 (K), D26.1 (K), D27.1 (K), D28.1 (K), D29.1 (K), D30.1 (K), D31.1 (K); also elsewhere on the board
row2: D32.1 (K), D33.1 (K), D34.1 (K), D35.1 (K), D36.1 (K), D37.1 (K), D38.1 (K), D39.1 (K), D40.1 (K), D41.1 (K), D42.1 (K), D43.1 (K), D44.1 (K), D45.1 (K), D46.1 (K), D47.1 (K); also elsewhere on the board
row3: D48.1 (K), D49.1 (K), D50.1 (K), D51.1 (K), D52.1 (K), D53.1 (K), D54.1 (K), D55.1 (K), D56.1 (K), D57.1 (K), D58.1 (K), D59.1 (K), D60.1 (K), D61.1 (K), D62.1 (K); also elsewhere on the board
row4: D63.1 (K), D64.1 (K), D65.1 (K), D66.1 (K), D67.1 (K), D68.1 (K), D69.1 (K), D70.1 (K), D71.1 (K), D72.1 (K), D73.1 (K), D74.1 (K), D75.1 (K), D76.1 (K); also elsewhere on the board
row5: D77.1 (K), D78.1 (K), D79.1 (K), D80.1 (K), D81.1 (K), D82.1 (K), D83.1 (K), D84.1 (K), D85.1 (K), D86.1 (K); also elsewhere on the board

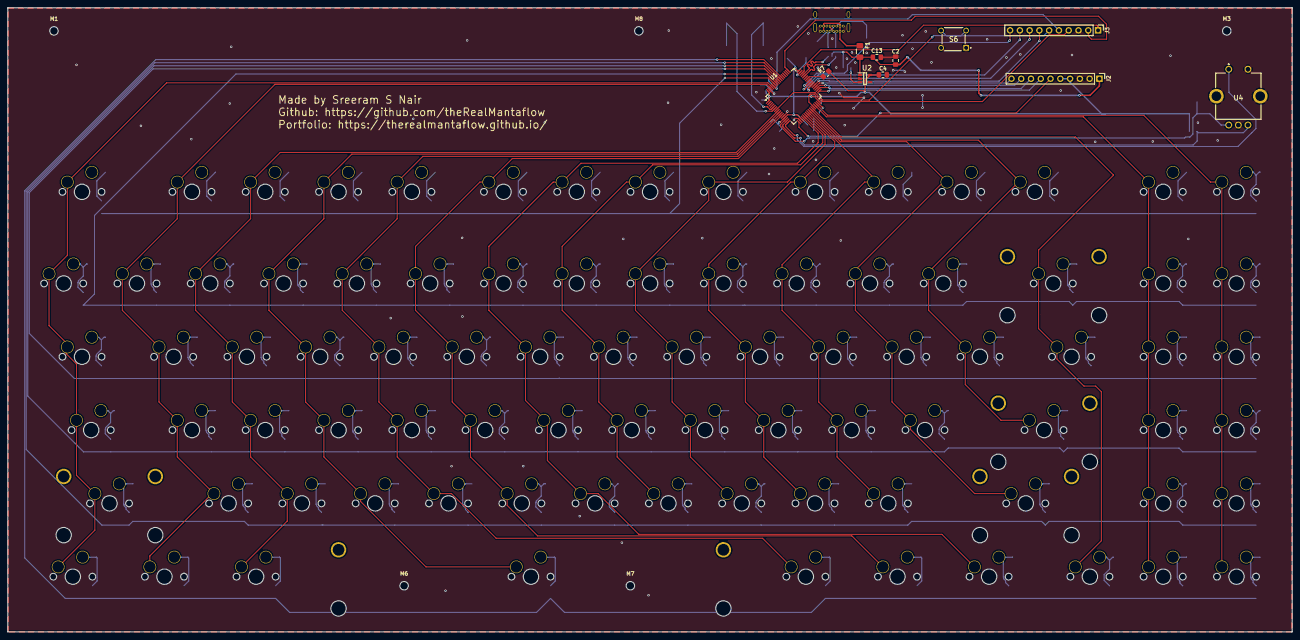
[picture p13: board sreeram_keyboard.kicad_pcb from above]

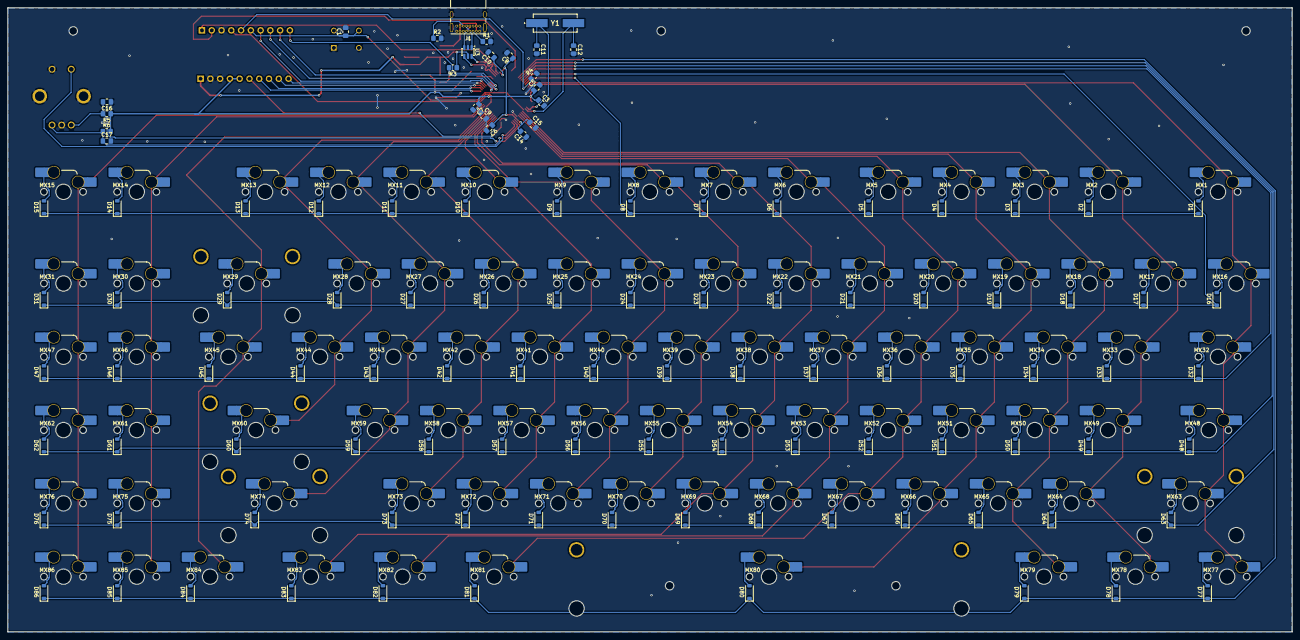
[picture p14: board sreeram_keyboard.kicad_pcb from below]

Board: 2 copper layers, 333.8 x 162.2 mm, 216 parts (195 on the bottom side), 141 nets.

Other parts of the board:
M1, M3, M6, M7, M8: MountingHole_2.2mm_M2
